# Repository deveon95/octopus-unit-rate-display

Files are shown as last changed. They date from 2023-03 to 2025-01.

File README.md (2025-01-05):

# Octopus Unit Rate Display for ESP32

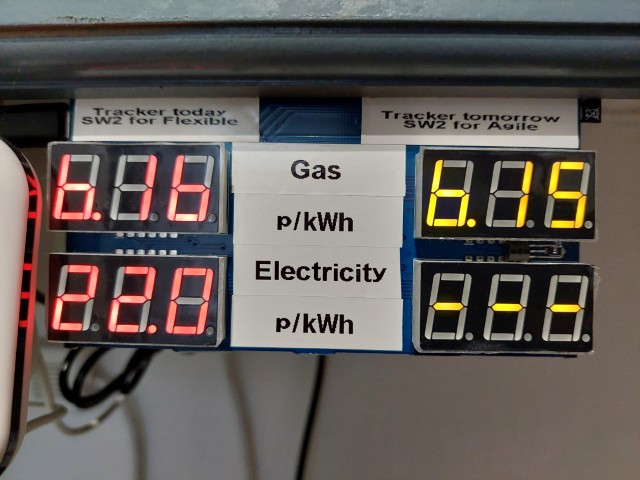
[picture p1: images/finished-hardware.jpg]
photo of the hardware


This project gets JSON data from https://octopus.energy

The JSON data is parsed and used to get today's gas and electricity unit rates for the **Tracker** tariff and/or the current **Flexible** prices and/or the current **Agile** prices.

Prices are displayed on two or more 3-digit 7-segment displays to two decimal places if the unit rate is less than 10.00, or one decimal place if the unit rate is greater than or equal to 10.00. Values greater than or equal to 100.00 are displayed with no decimal places.

Negative prices are also supported. In such an event, the first digit will be used for the '-' character.

# Installation

You'll need to install esp-idf to build this project.

```
git clone https://github.com/deveon95/octopus-unit-rate-display
cd esp-idf-json/json-http-client2
chmod 777 getpem.sh
./getpem.sh
idf.py menuconfig
idf.py build flash monitor
```

The getpem.sh script gets the https certificate for octopus.energy. HTTPS is mandatory to use the Octopus API, and this step cannot be skipped! The script does work on Windows as well as Linux; you can run the script with Windows Subsystem for Linux, and you may already be able to run it without installing anything extra if you've installed Git for Windows.

# Configuration
The configuration is opened by running idf.py menuconfig.

You'll need to set the wifi SSID and password so that the ESP32 can connect to the internet, and the tariff codes for the most accurate prices. Note that the latest version of the code has a few extra options for tariff codes not shown in the old screenshots because it has support for more tariffs. The 'ENABLE' options that show up in the latest version of the code should be set to 1 for tariffs that are desired to be displayed or 0 for tariffs to exclude.

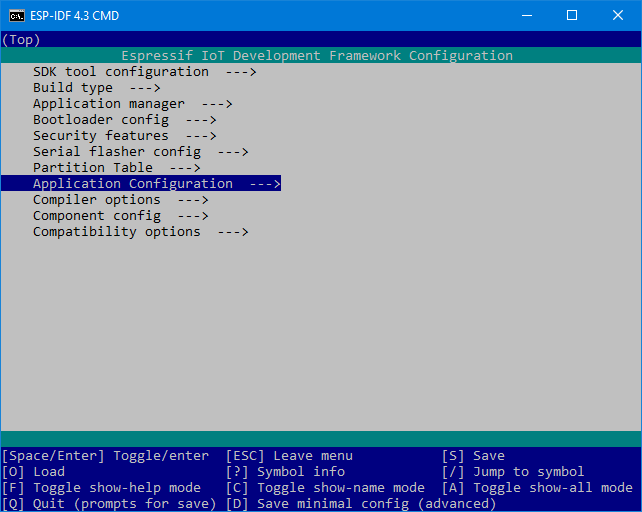
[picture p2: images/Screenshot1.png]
config-top

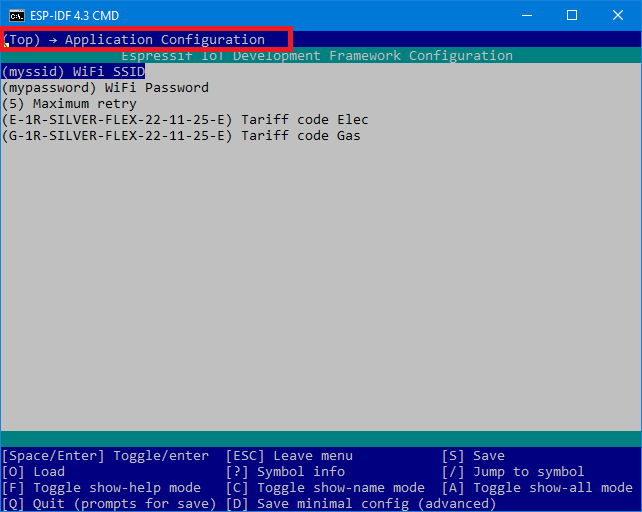
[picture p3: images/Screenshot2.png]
config-app


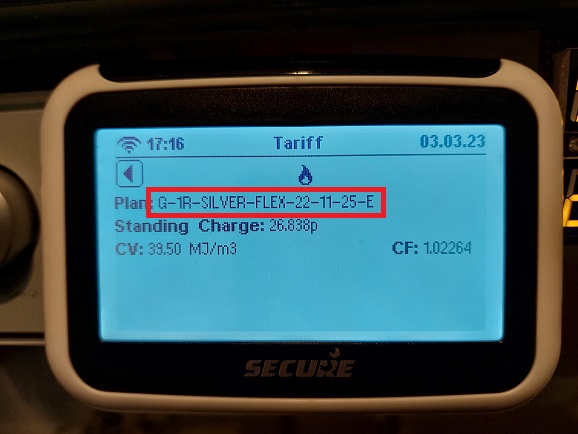
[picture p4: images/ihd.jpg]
finding the tariff on the ihd


To see the console output, set the log verbosity to Info. To disable console output, set to None.

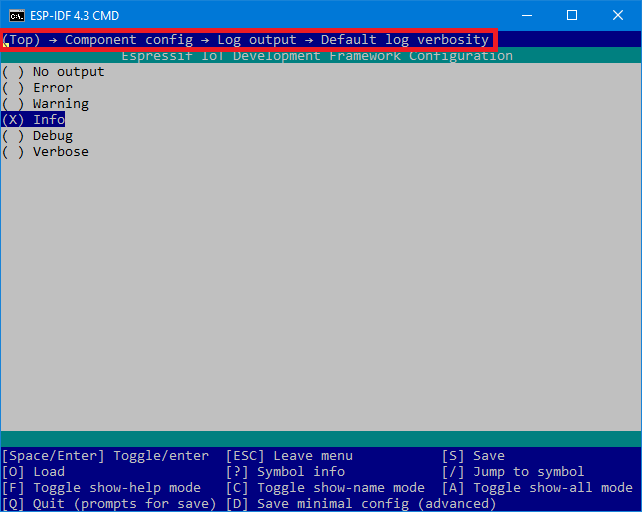
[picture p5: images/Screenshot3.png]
config-log


# Console output   
When enabled in the configuration, the console output will show all the unit rates returned by the server, usually for every day of the current month.

# Hardware schematic
See the KiCad design. The board can be mostly assembled by JLCPCB with displays of your choosing added by hand later.

The board and firmware supports up to 8 3-digit 7-segment displays. The lower half of the board can be broken off to give a more compact 4 display version shown in the photo.

For further details of the project, please see [my blog](https://nick-elec.blogspot.com/2023/03/esp32-based-octopus-tracker-unit-rate.html)

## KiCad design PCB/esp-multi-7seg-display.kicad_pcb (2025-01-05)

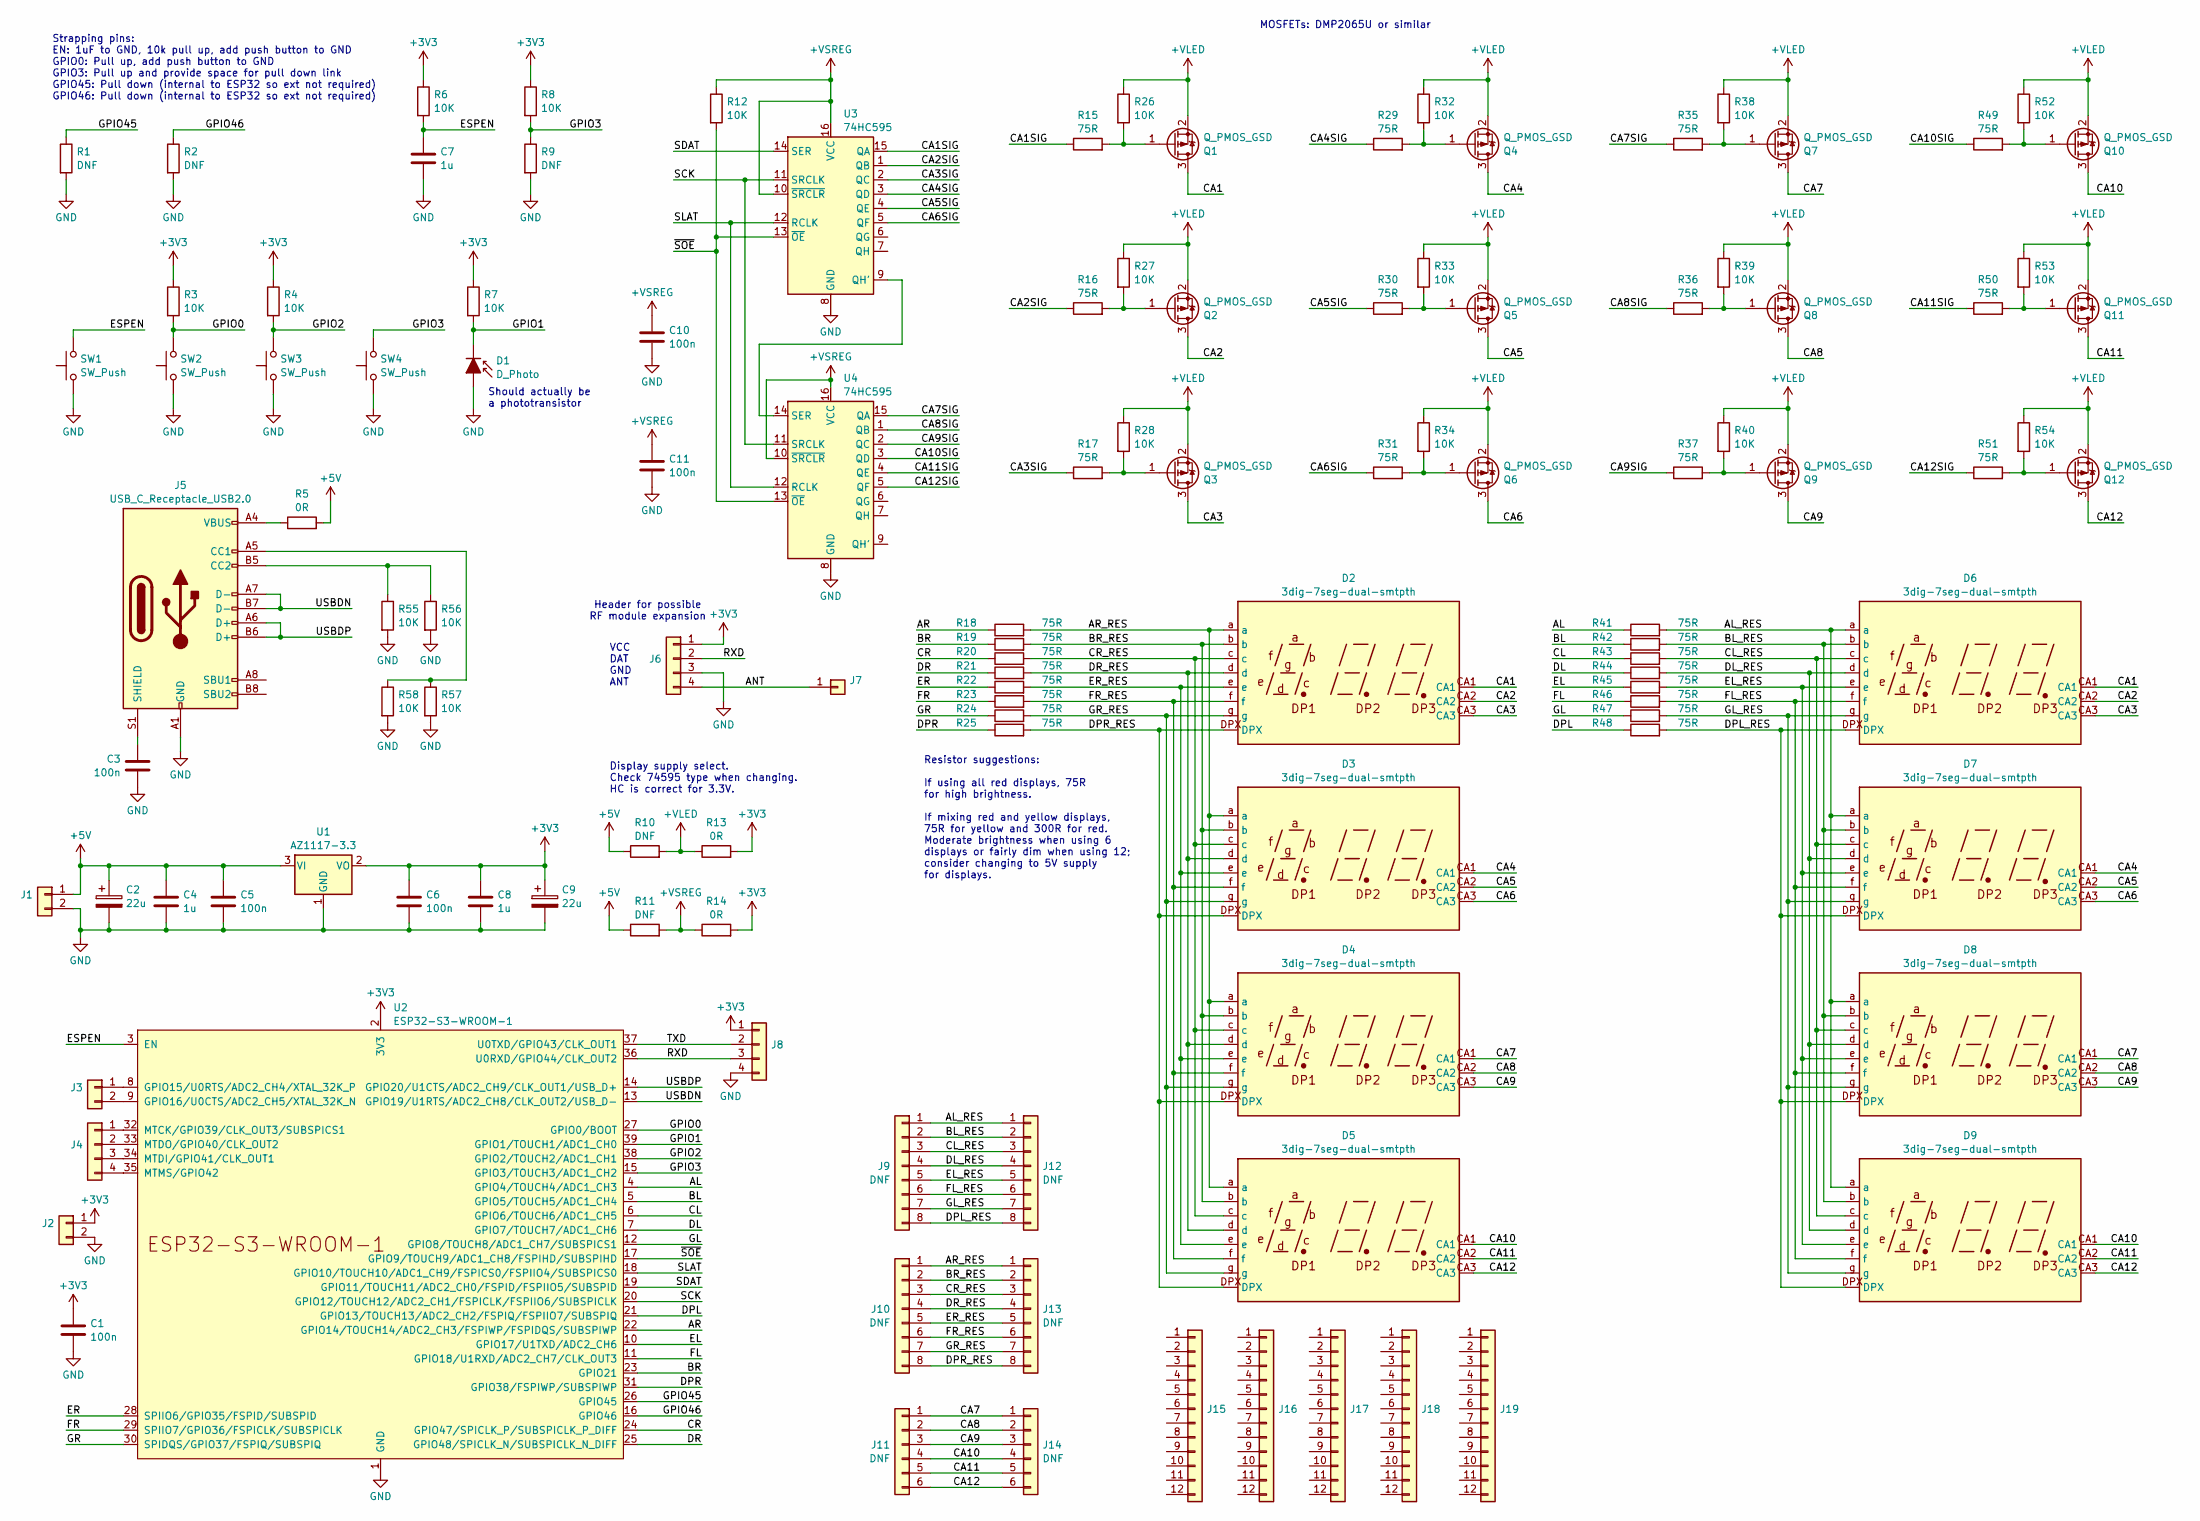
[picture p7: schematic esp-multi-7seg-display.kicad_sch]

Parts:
C1, C3, C5, C6, C10, C11: 100n; C_0603_1608Metric_Pad1.08x0.95mm_HandSolder; LCSC Part # C14663
C2, C9: 22u; CP_Elec_6.3x5.4; LCSC Part # C3646800
C4, C7, C8: 1u; C_0603_1608Metric_Pad1.08x0.95mm_HandSolder; LCSC Part # C15849
D1: D_Photo; LED_0805_2012Metric_Pad1.15x1.40mm_HandSolder
D2, D3, D4, D5, D6, D7, D8, D9: 3dig-7seg-dual-smtpth; LCSC Part # C226010
J1, J2, J3: DNF; PinHeader_1x02_P2.54mm_Vertical
J4, J6, J8: DNF; PinHeader_1x04_P2.54mm_Vertical
J5: USB_C_Receptacle_USB2.0; USB_C_Receptacle_G-Switch_GT-USB-7010ASV; LCSC Part # C2988369
J7: DNF; SolderWirePad_1x01_SMD_1x2mm
J9, J10, J12, J13: DNF; PinHeader_2x04_P2.54mm_Vertical_SMD
J11, J14: DNF; PinHeader_2x03_P2.54mm_Vertical_SMD
J15, J16, J17, J18, J19: DNF; PinHeader_1x12_P2.54mm_Vertical
Q1, Q2, Q3, Q4, Q5, Q6, Q7, Q8, Q9, Q10, Q11, Q12: Q_PMOS_GSD; SOT-23; LCSC Part # C10487
R1, R2, R9, R10, R11: DNF; R_0603_1608Metric_Pad0.98x0.95mm_HandSolder
R3, R4, R6, R7, R8, R12, R26, R27, R28, R32, R33, R34, R38, R39, R40, R52, R53, R54, R55, R56, R57, R58: 10K; R_0603_1608Metric_Pad0.98x0.95mm_HandSolder; LCSC Part # C465721
R5, R13, R14: 0R; R_0603_1608Metric_Pad0.98x0.95mm_HandSolder; LCSC Part # C103195
R15, R16, R17, R18, R19, R20, R21, R22, R23, R24, R25, R29, R30, R31, R35, R36, R37, R41, R42, R43, R44, R45, R46, R47, R48, R49, R50, R51: 75R; R_0603_1608Metric_Pad0.98x0.95mm_HandSolder; LCSC Part # C328376
SW1, SW2, SW3, SW4: SW_Push; SW_Push_1P1T_NO_6x6mm_H9.5mm; LCSC Part # C2909692
U1: AZ1117-3.3; SOT-223-3_TabPin2; LCSC Part # C6186
U2: ESP32-S3-WROOM-1; LCSC Part # C2913198
U3, U4: 74HC595; SO-16_5.3x10.2mm_P1.27mm; LCSC Part # C5947

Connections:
+3V3: C1.1, C6.1, C8.1, C9.1, J2.1, J6.1, J8.1, R3.1, R4.1, R6.1, R7.1, R8.1, R13.2, R14.2, U1.2 (VO), U2.2 (3V3)
+5V: C2.1, C4.1, C5.1, J1.1, R5.2, R10.1, R11.1, U1.3 (VI)
+VLED: Q1.2 (S), Q2.2 (S), Q3.2 (S), Q4.2 (S), Q5.2 (S), Q6.2 (S), Q7.2 (S), Q8.2 (S), Q9.2 (S), Q10.2 (S), Q11.2 (S), Q12.2 (S), R10.2, R13.1, R26.1, R27.1, R28.1, R32.1, R33.1, R34.1, R38.1, R39.1, R40.1, R52.1, R53.1, R54.1
+VSREG: C10.1, C11.1, R11.2, R12.1, R14.1, U3.10 (~SRCLR), U3.16 (VCC), U4.10 (~SRCLR), U4.16 (VCC)
/AL: R41.1, U2.4 (GPIO4/TOUCH4/ADC1_CH3)
/AL_RES: D6.a, D7.a, D8.a, D9.a, J9.1, J12.1, R41.2
/ANT: J6.4, J7.1
/AR: R18.1, U2.22 (GPIO14/TOUCH14/ADC2_CH3/FSPIWP/FSPIDQS/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)
/AR_RES: D2.a, D3.a, D4.a, D5.a, J10.1, J13.1, R18.2
/BL: R42.1, U2.5 (GPIO5/TOUCH5/ADC1_CH4)
/BL_RES: D6.b, D7.b, D8.b, D9.b, J9.2, J12.2, R42.2
/BR: R19.1, U2.23 (GPIO21)
/BR_RES: D2.b, D3.b, D4.b, D5.b, J10.2, J13.2, R19.2
/CA1: D2.CA1, D6.CA1, Q1.3 (D)
/CA1SIG: R15.1, U3.15 (QA)
/CA2: D2.CA2, D6.CA2, Q2.3 (D)
/CA2SIG: R16.1, U3.1 (QB)
/CA3: D2.CA3, D6.CA3, Q3.3 (D)
/CA3SIG: R17.1, U3.2 (QC)
/CA4: D3.CA1, D7.CA1, Q4.3 (D)
/CA4SIG: R29.1, U3.3 (QD)
/CA5: D3.CA2, D7.CA2, Q5.3 (D)
/CA5SIG: R30.1, U3.4 (QE)
/CA6: D3.CA3, D7.CA3, Q6.3 (D)
/CA6SIG: R31.1, U3.5 (QF)
/CA7: D4.CA1, D8.CA1, J11.1, J14.1, Q7.3 (D)
/CA7SIG: R35.1, U4.15 (QA)
/CA8: D4.CA2, D8.CA2, J11.2, J14.2, Q8.3 (D)
/CA8SIG: R36.1, U4.1 (QB)
/CA9: D4.CA3, D8.CA3, J11.3, J14.3, Q9.3 (D)
/CA9SIG: R37.1, U4.2 (QC)
/CA10: D5.CA1, D9.CA1, J11.4, J14.4, Q10.3 (D)
/CA10SIG: R49.1, U4.3 (QD)
/CA11: D5.CA2, D9.CA2, J11.5, J14.5, Q11.3 (D)
/CA11SIG: R50.1, U4.4 (QE)
/CA12: D5.CA3, D9.CA3, J11.6, J14.6, Q12.3 (D)
/CA12SIG: R51.1, U4.5 (QF)
/CL: R43.1, U2.6 (GPIO6/TOUCH6/ADC1_CH5)
/CL_RES: D6.c, D7.c, D8.c, D9.c, J9.3, J12.3, R43.2
/CR: R20.1, U2.24 (GPIO47/SPICLK_P/SUBSPICLK_P_DIFF)
/CR_RES: D2.c, D3.c, D4.c, D5.c, J10.3, J13.3, R20.2
/DL: R44.1, U2.7 (GPIO7/TOUCH7/ADC1_CH6)
/DL_RES: D6.d, D7.d, D8.d, D9.d, J9.4, J12.4, R44.2
/DPL: R48.1, U2.21 (GPIO13/TOUCH13/ADC2_CH2/FSPIQ/FSPIIO7/S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)
/DPL_RES: D6.DPX, D7.DPX, D8.DPX, D9.DPX, J9.8, J12.8, R48.2
/DPR: R25.1, U2.31 (GPIO38/FSPIWP/SUBSPIWP)
/DPR_RES: D2.DPX, D3.DPX, D4.DPX, D5.DPX, J10.8, J13.8, R25.2
/DR: R21.1, U2.25 (GPIO48/SPICLK_N/SUBSPICLK_N_DIFF)
/DR_RES: D2.d, D3.d, D4.d, D5.d, J10.4, J13.4, R21.2
/EL: R45.1, U2.10 (GPIO17/U1TXD/ADC2_CH6)
/EL_RES: D6.e, D7.e, D8.e, D9.e, J9.5, J12.5, R45.2
/ER: R22.1, U2.28 (SPIIO6/GPIO35/FSPID/SUBSPID)
/ER_RES: D2.e, D3.e, D4.e, D5.e, J10.5, J13.5, R22.2
/ESPEN: C7.1, R6.2, SW1.2, U2.3 (EN)
/FL: R46.1, U2.11 (GPIO18/U1RXD/ADC2_CH7/CLK_OUT3)
/FL_RES: D6.f, D7.f, D8.f, D9.f, J9.6, J12.6, R46.2
/FR: R23.1, U2.29 (SPIIO7/GPIO36/FSPICLK/SUBSPICLK)
/FR_RES: D2.f, D3.f, D4.f, D5.f, J10.6, J13.6, R23.2
/GL: R47.1, U2.12 (GPIO8/TOUCH8/ADC1_CH7/SUBSPICS1)
/GL_RES: D6.g, D7.g, D8.g, D9.g, J9.7, J12.7, R47.2
/GPIO0: R3.2, SW2.2, U2.27 (GPIO0/BOOT)
/GPIO1: D1.1 (K), R7.2, U2.39 (GPIO1/TOUCH1/ADC1_CH0)
/GPIO2: R4.2, SW3.2, U2.38 (GPIO2/TOUCH2/ADC1_CH1)
/GPIO3: R8.2, R9.1, SW4.2, U2.15 (GPIO3/TOUCH3/ADC1_CH2)
/GPIO45: R1.1, U2.26 (GPIO45)
/GPIO46: R2.1, U2.16 (GPIO46)
/GR: R24.1, U2.30 (SPIDQS/GPIO37/FSPIQ/SUBSPIQ)
/GR_RES: D2.g, D3.g, D4.g, D5.g, J10.7, J13.7, R24.2
/RXD: J6.2, J8.3, U2.36 (U0RXD/GPIO44/CLK_OUT2)
/SCK: U2.20 (GPIO12/TOUCH12/ADC2_CH1/FSPICLK/FSPIIO6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), U3.11 (SRCLK), U4.11 (SRCLK)
/SDAT: U2.19 (GPIO11/TOUCH11/ADC2_CH0/FSPID/FSPIIO5/S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), U3.14 (SER)
/SLAT: U2.18 (GPIO10/TOUCH10/ADC1_CH9/FSPICS0/FSPIIO4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), U3.12 (RCLK), U4.12 (RCLK)
/TXD: J8.2, U2.37 (U0TXD/GPIO43/CLK_OUT1)
/USBDN: J5.A7 (D-), J5.B7 (D-), U2.13 (GPIO19/U1RTS/ADC2_CH8/CLK_OUT2/USB_D-)
/USBDP: J5.A6 (D+), J5.B6 (D+), U2.14 (GPIO20/U1CTS/ADC2_CH9/CLK_OUT1/USB_D+)
/~SOE: R12.2, U2.17 (GPIO9/TOUCH9/ADC1_CH8/FSPIHD/SUBSPIHD), U3.13 (~OE), U4.13 (~OE)
GND: C1.2, C2.2, C3.2, C4.2, C5.2, C6.2, C7.2, C8.2, C9.2, C10.2, C11.2, D1.2 (A), J1.2, J2.2, J5.A1 (GND), J5.A12 (GND), J5.B1 (GND), J5.B12 (GND), J6.3, J8.4, R1.2, R2.2, R9.2, R55.2, R56.2, R57.2, R58.2, SW1.1, SW2.1, SW3.1, SW4.1, U1.1 (GND), U2.1 (GND), U2.40 (GND), U2.41 (GND), U3.8 (GND), U4.8 (GND)
unnamed: J3.1, U2.8 (GPIO15/U0RTS/ADC2_CH4/XTAL_32K_P)
unnamed: J3.2, U2.9 (GPIO16/U0CTS/ADC2_CH5/XTAL_32K_N)
unnamed: J4.1, U2.32 (MTCK/GPIO39/CLK_OUT3/SUBSPICS1)
unnamed: J4.2, U2.33 (MTDO/GPIO40/CLK_OUT2)
unnamed: J4.3, U2.34 (MTDI/GPIO41/CLK_OUT1)
unnamed: J4.4, U2.35 (MTMS/GPIO42)
unnamed: J5.A5 (CC1), R57.1, R58.1
unnamed: J5.B5 (CC2), R55.1, R56.1
unnamed: C3.1, J5.S1 (SHIELD)
unnamed: J5.A4 (VBUS), J5.A9 (VBUS), J5.B4 (VBUS), J5.B9 (VBUS), R5.1
unnamed: Q1.1 (G), R15.2, R26.2
unnamed: Q2.1 (G), R16.2, R27.2
unnamed: Q3.1 (G), R17.2, R28.2
unnamed: Q4.1 (G), R29.2, R32.2
unnamed: Q5.1 (G), R30.2, R33.2
unnamed: Q6.1 (G), R31.2, R34.2
unnamed: Q7.1 (G), R35.2, R38.2
unnamed: Q8.1 (G), R36.2, R39.2
unnamed: Q9.1 (G), R37.2, R40.2
unnamed: Q10.1 (G), R49.2, R52.2
unnamed: Q11.1 (G), R50.2, R53.2
unnamed: Q12.1 (G), R51.2, R54.2
unnamed: U3.9 (QH'), U4.14 (SER)

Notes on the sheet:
VCC DAT GND ANT
MOSFETs: DMP2065U or similar
Resistor suggestions: If using all red displays, 75R for high brightness. If mixing red and yellow displays, 75R for yellow and 300R for red. Moderate brightness when using 6 displays or fairly dim when using 12; consider changing to 5V supply for displays.
Header for possible RF module expansion
Should actually be a phototransistor
Strapping pins: EN: 1uF to GND, 10k pull up, add push button to GND GPIO0: Pull up, add push button to GND GPIO3: Pull up and provide space for pull down link GPIO45: Pull down (internal to ESP32 so ext not required) GPIO46: Pull down (internal to ESP32 so ext not required)
Display supply select. Check 74595 type when changing. HC is correct for 3.3V.

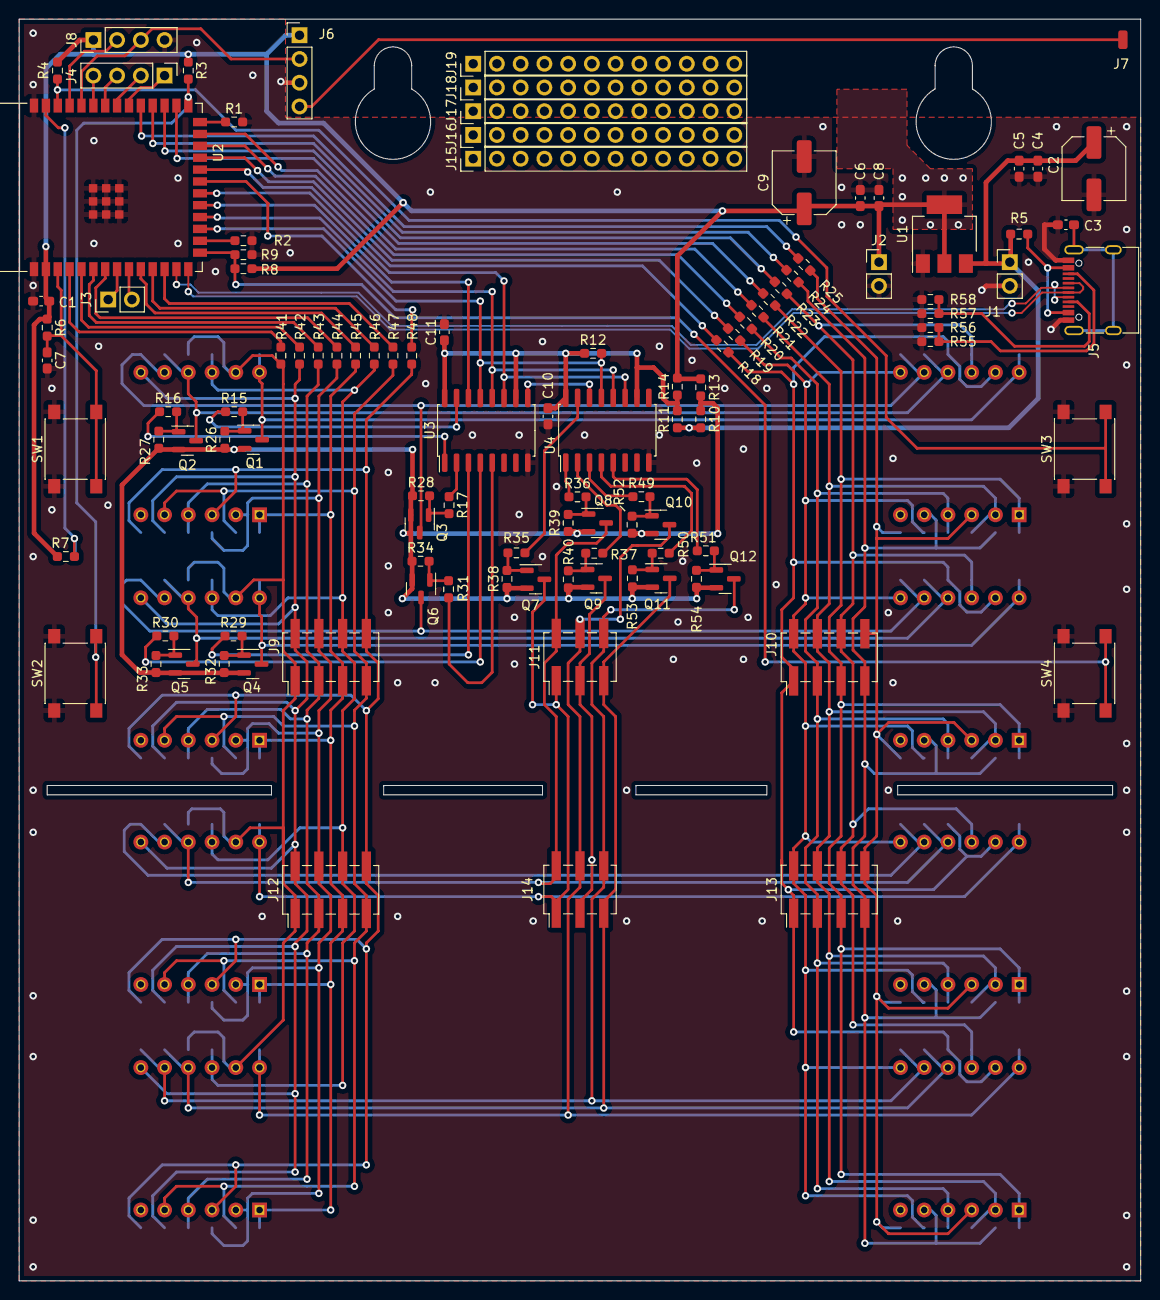
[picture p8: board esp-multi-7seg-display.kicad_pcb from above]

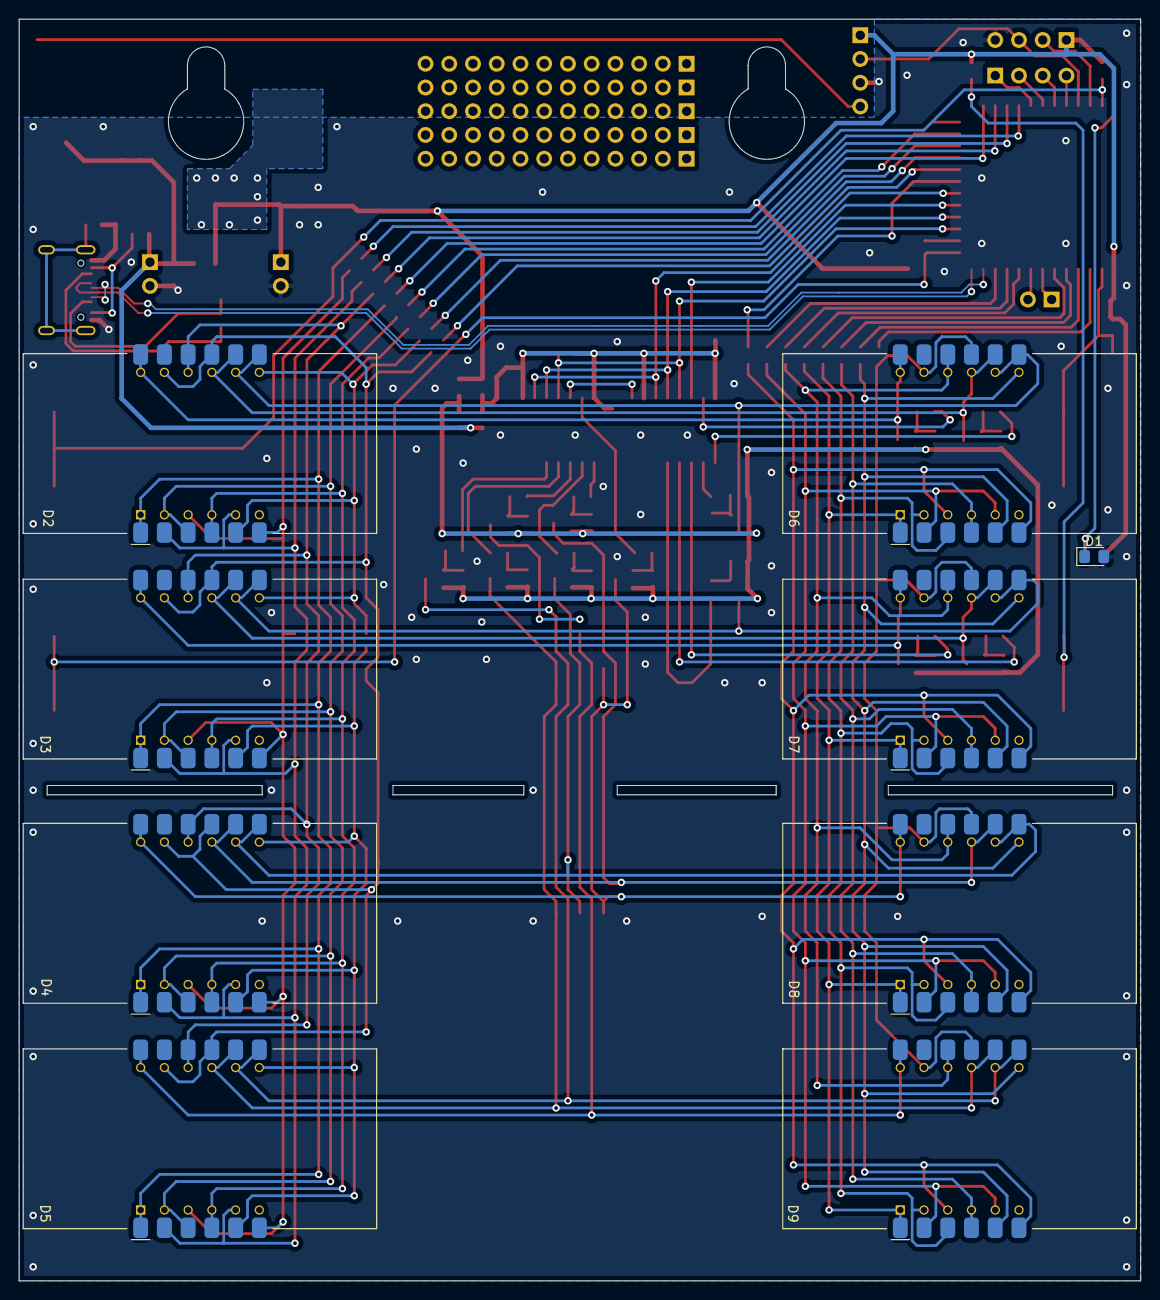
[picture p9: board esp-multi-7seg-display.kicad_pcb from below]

Board: 2 copper layers, 120.0 x 135.0 mm, 117 parts (9 on the bottom side), 100 nets.

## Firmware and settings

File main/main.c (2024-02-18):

/* Octopus Tracker Tariff Display for ESP32 / ESP-IDF
 *
 * Copyright (c) 2023 Nick Schollar
 * Licenced under MIT Licence
 *
 * Displays today's gas and electricity price for the tariff code specified in menuconfig
 * on two 3-digit common anode 7-segment displays. The tariff code is specific to your region.
 *
 * This program fetches the data from the server using a public API once per hour.
 * A certificate file is needed to connect to the server because HTTPS is mandatory.
 *
 * Wi-Fi SSID and password are specified in menuconfig.
 *
 * Self-diagnostics:
 * No dashes or decimal points: Program not running or displays connected incorrectly
 *   Check display wiring.
 * No dashes (only decimal points): Not connected to wifi
 *   Check SSID and password.
 * One dash on the display: Connected to wifi, time not synchronised yet
 *   Time is taken from HTTP response header, so this suggests unable to connect to internet.
 * Two dashes on the display: Time synchronised, prices not obtained yet
 *   API may have changed. Try tariff URL in a browser.
 */
#include "freertos/FreeRTOS.h"
#include "freertos/task.h"
#include "freertos/event_groups.h"
#include "freertos/ringbuf.h"
#include "esp_system.h"
#include "esp_wifi.h"
#include "esp_event.h"
#include "esp_log.h"
#include "nvs_flash.h"
#include "time.h"
#include "driver/gpio.h"
#include "hal/gpio_ll.h"
#include "driver/timer.h"
#include "driver/adc.h"

#include "lwip/err.h"
#include "lwip/sys.h"

#include "esp_http_client.h" 
#include "esp_tls.h" 
#include "cJSON.h"

#define SR_DELAY_US 1
#define NUM_OF_ANODES 16
#define ANODES_IN_USE 0b0000000000111111
//#define ANODES_IN_USE 0b0011111100111111

#define pin_segAR 14
#define pin_segBR 21
#define pin_segCR 47
#define pin_segDR 48
#define pin_segER 35
#define pin_segFR 36
#define pin_segGR 37
#define pin_segDPR 38
#define pin_segAL 4
#define pin_segBL 5
#define pin_segCL 6
#define pin_segDL 7
#define pin_segEL 17
#define pin_segFL 18
#define pin_segGL 8
#define pin_segDPL 13

#define pin_SOE 9
#define pin_SLAT 10
#define pin_SDAT 11
#define pin_SCK 12

#define pin_BUTTON2 0
#define pin_BUTTON3 2
#define pin_BUTTON4 3

#define TIMER_DIVIDER         (16)  //  Hardware timer clock divider
#define TIMER_SCALE           ((ets_get_apb_freq() / 10000)/ TIMER_DIVIDER)  // convert counter value to seconds

typedef struct {
    int timer_group;
    int timer_idx;
    int alarm_interval;
    bool auto_reload;
} timer_info_t;

//spi_device_handle_t spihandle;

// Set to True if the time was updated successfully
bool timeSet = false;
bool wifi_connected = false;
// Need to change this to separate ones for gas and elec
bool got_gas_unit_rate = false;
bool got_elec_unit_rate = false;
bool got_gas_tomorrow_unit_rate = false;
bool got_elec_tomorrow_unit_rate = false;
bool got_gas_flex_unit_rate = false;
bool got_elec_flex_unit_rate = false;
bool got_elec_agile_unit_rate = false;
#define TARIFF_TYPE_TRACKER 0
#define TARIFF_TYPE_FLEXIBLE 1
#define TARIFF_TYPE_AGILE 2
#define TARIFF_TYPE_TRACKER_TOMORROW 3

double gas_unit_rate = 0.0;
double elec_unit_rate = 0.0;
double gas_tomorrow_unit_rate = 0.0;
double elec_tomorrow_unit_rate = 0.0;
double gas_flex_unit_rate = 0.0;
double elec_flex_unit_rate = 0.0;
double elec_agile_rates[48];
uint64_t elec_agile_validity = 0;
uint8_t agile_time = 0;

#define FETCHER_WDOG_LIMIT_IN_SECONDS (60*15)

#define NUMBER_OF_BRIGHTNESS_SETTINGS 4
#define BRIGHTNESS_HYSTERESIS 100
// brightness of the display (0 to 3)
uint8_t display_brightness = 3;

#define ADC_FILTER_LENGTH 30
#define ADC_MAX_VALUE 4095
#define ADC_HYSTERESIS 200
static const adc_channel_t channel = ADC_CHANNEL_0;     //GPIO1 for ADC1
static const adc_bits_width_t width = ADC_WIDTH_BIT_12;
static const adc_atten_t atten = ADC_ATTEN_DB_11;
//static const adc_unit_t unit = ADC_UNIT_1;


/* FreeRTOS event group to signal when we are connected*/
static EventGroupHandle_t s_wifi_event_group;

/* The event group allows multiple bits for each event, but we only care about two events:
 * - we are connected to the AP with an IP
 * - we failed to connect after the maximum amount of retries */
#define WIFI_CONNECTED_BIT BIT0
#define WIFI_FAIL_BIT BIT1

static const char *TAG = "JSON";
static const char *TAG_FW = "FWD";
static const char *TAG_ADC = "ADC";

static int s_retry_num = 0;

/* Root cert for octopus.energy.com, taken from octopus_energy_root_cert.pem

	 The PEM file was extracted from the output of this command:
	 openssl s_client -showcerts -connect octopus.energy:443 </dev/null >hoge

	 The CA root cert is the last cert given in the chain of certs.

	 To embed it in the app binary, the PEM file is named
	 in the component.mk COMPONENT_EMBED_TXTFILES variable.
*/
extern const char octopus_energy_root_cert_pem_start[] asm("_binary_octopus_energy_root_cert_pem_start");
//extern const char octopus_energy_root_cert_pem_end[]	asm("_binary_octopus_energy_root_cert_pem_end");


esp_err_t _http_event_handler(esp_http_client_event_t *evt)
{
    struct tm time_struct;
    struct timeval timeval_struct;
    
	static char *output_buffer;  // Buffer to store response of http request from event handler
	static int output_len;		 // Stores number of bytes read
	switch(evt->event_id) {
		case HTTP_EVENT_ERROR:
			ESP_LOGD(TAG, "HTTP_EVENT_ERROR");
			break;
		case HTTP_EVENT_ON_CONNECTED:
			ESP_LOGD(TAG, "HTTP_EVENT_ON_CONNECTED");
			break;
		case HTTP_EVENT_HEADER_SENT:
			ESP_LOGD(TAG, "HTTP_EVENT_HEADER_SENT");
			break;
		case HTTP_EVENT_ON_HEADER:
			ESP_LOGD(TAG, "HTTP_EVENT_ON_HEADER, key=%s, value=%s", evt->header_key, evt->header_value);
            if (strcmp(evt->header_key, "Date") == 0)
            {
                ESP_LOGI(TAG, "Date header found: %s", evt->header_value);
                strptime(evt->header_value, "%a, %d %b %Y %H:%M:%S %Z", &time_struct);
                ESP_LOGI(TAG, "Time struct written: %d-%d-%d %d:%d:%d", time_struct.tm_year, time_struct.tm_mon, time_struct.tm_mday, time_struct.tm_hour, time_struct.tm_min, time_struct.tm_sec);
                timeval_struct.tv_sec = mktime(&time_struct);
                timeval_struct.tv_usec = 0;
                // tv_sec becomes -1 if mktime failed to convert the time struct into a time value
                if (timeval_struct.tv_sec > 0)
                {
                    timeSet = true;
                    ESP_LOGI(TAG, "RTC Seconds Since Epoch: %lld", timeval_struct.tv_sec);
                    ESP_LOGI(TAG, "RTC set, returned: %d", settimeofday(&timeval_struct, NULL));
                }
            }
			break;
		case HTTP_EVENT_ON_DATA:
			ESP_LOGD(TAG, "HTTP_EVENT_ON_DATA, len=%d", evt->data_len);
			//ESP_LOGD(TAG, "HTTP_EVENT_ON_DATA, content_length=%d", esp_http_client_get_content_length(evt->client));
			ESP_LOGD(TAG, "HTTP_EVENT_ON_DATA, output_len=%d", output_len);
			// If user_data buffer is configured, copy the response into the buffer
			if (evt->user_data) {
				memcpy(evt->user_data + output_len, evt->data, evt->data_len);
			} else {
				if (output_buffer == NULL && esp_http_client_get_content_length(evt->client) > 0) {
					output_buffer = (char *) malloc(esp_http_client_get_content_length(evt->client));
					output_len = 0;
					if (output_buffer == NULL) {
						ESP_LOGE(TAG, "Failed to allocate memory for output buffer");
						return ESP_FAIL;
					}
				}
				memcpy(output_buffer + output_len, evt->data, evt->data_len);
			}
			output_len += evt->data_len;
			break;
		case HTTP_EVENT_ON_FINISH:
			ESP_LOGD(TAG, "HTTP_EVENT_ON_FINISH");
			if (output_buffer != NULL) {
				// Response is accumulated in output_buffer. Uncomment the below line to print the accumulated response
				// ESP_LOG_BUFFER_HEX(TAG, output_buffer, output_len);
				free(output_buffer);
				output_buffer = NULL;
			}
			output_len = 0;
			break;
		case HTTP_EVENT_DISCONNECTED:
			ESP_LOGD(TAG, "HTTP_EVENT_DISCONNECTED");
			int mbedtls_err = 0;
			esp_err_t err = esp_tls_get_and_clear_last_error(evt->data, &mbedtls_err, NULL);
			if (err != 0) {
				if (output_buffer != NULL) {
					free(output_buffer);
					output_buffer = NULL;
				}
				output_len = 0;
				ESP_LOGE(TAG, "Last esp error code: 0x%x", err);
				ESP_LOGE(TAG, "Last mbedtls failure: 0x%x", mbedtls_err);
			}
			break;
#if ESP_IDF_VERSION >= ESP_IDF_VERSION_VAL(5, 0, 0)
		case HTTP_EVENT_REDIRECT:
			ESP_LOGD(TAG, "HTTP_EVENT_REDIRECT");
			break;
#endif
	}
	return ESP_OK;
}

static void event_handler(void* arg, esp_event_base_t event_base,
																int32_t event_id, void* event_data)
{
	if (event_base == WIFI_EVENT && event_id == WIFI_EVENT_STA_START) {
		esp_wifi_connect();
	} else if (event_base == WIFI_EVENT && event_id == WIFI_EVENT_STA_DISCONNECTED) {
		if (s_retry_num < CONFIG_ESP_MAXIMUM_RETRY) {
				esp_wifi_connect();
				s_retry_num++;
				ESP_LOGI(TAG, "retry to connect to the AP");
		} else {
				xEventGroupSetBits(s_wifi_event_group, WIFI_FAIL_BIT);
		}
		ESP_LOGI(TAG,"connect to the AP fail");
        wifi_connected = false;
	} else if (event_base == IP_EVENT && event_id == IP_EVENT_STA_GOT_IP) {
		ip_event_got_ip_t* event = (ip_event_got_ip_t*) event_data;
		ESP_LOGI(TAG, "got ip:" IPSTR, IP2STR(&event->ip_info.ip));
		s_retry_num = 0;
		xEventGroupSetBits(s_wifi_event_group, WIFI_CONNECTED_BIT);
        wifi_connected = true;
	}
}

void wifi_init_sta(void)
{
	s_wifi_event_group = xEventGroupCreate();

	ESP_ERROR_CHECK(esp_netif_init());

	ESP_ERROR_CHECK(esp_event_loop_create_default());
	esp_netif_create_default_wifi_sta();

	wifi_init_config_t cfg = WIFI_INIT_CONFIG_DEFAULT();
	ESP_ERROR_CHECK(esp_wifi_init(&cfg));

	esp_event_handler_instance_t instance_any_id;
	esp_event_handler_instance_t instance_got_ip;
	ESP_ERROR_CHECK(esp_event_handler_instance_register(WIFI_EVENT,
									ESP_EVENT_ANY_ID,
									&event_handler,
									NULL,
									&instance_any_id));
	ESP_ERROR_CHECK(esp_event_handler_instance_register(IP_EVENT,
									IP_EVENT_STA_GOT_IP,
									&event_handler,
									NULL,
									&instance_got_ip));

	wifi_config_t wifi_config = {
		.sta = {
			.ssid = CONFIG_ESP_WIFI_SSID,
			.password = CONFIG_ESP_WIFI_PASSWORD,
			/* Setting a password implies station will connect to all security modes including WEP/WPA.
			 * However these modes are deprecated and not advisable to be used. Incase your Access point
			 * doesn't support WPA2, these mode can be enabled by commenting below line */
			.threshold.authmode = WIFI_AUTH_WPA2_PSK,

			.pmf_cfg = {
				.capable = true,
				.required = false
			},
		},
	};
	ESP_ERROR_CHECK(esp_wifi_set_mode(WIFI_MODE_STA) );
	ESP_ERROR_CHECK(esp_wifi_set_config(WIFI_IF_STA, &wifi_config) );
	ESP_ERROR_CHECK(esp_wifi_start() );

	ESP_LOGI(TAG, "wifi_init_sta finished.");

	/* Waiting until either the connection is established (WIFI_CONNECTED_BIT) or connection failed for the maximum
	 * number of re-tries (WIFI_FAIL_BIT). The bits are set by event_handler() (see above) */
	EventBits_t bits = xEventGroupWaitBits(s_wifi_event_group,
		WIFI_CONNECTED_BIT | WIFI_FAIL_BIT,
		pdFALSE,
		pdFALSE,
		portMAX_DELAY);

	/* xEventGroupWaitBits() returns the bits before the call returned, hence we can test which event actually
	 * happened. */
	if (bits & WIFI_CONNECTED_BIT) {
		ESP_LOGI(TAG, "connected to ap SSID:%s password:%s", CONFIG_ESP_WIFI_SSID, CONFIG_ESP_WIFI_PASSWORD);
	} else if (bits & WIFI_FAIL_BIT) {
		ESP_LOGI(TAG, "Failed to connect to SSID:%s, password:%s", CONFIG_ESP_WIFI_SSID, CONFIG_ESP_WIFI_PASSWORD);
	} else {
		ESP_LOGE(TAG, "UNEXPECTED EVENT");
	}

	/* The event will not be processed after unregister */
	ESP_ERROR_CHECK(esp_event_handler_instance_unregister(IP_EVENT, IP_EVENT_STA_GOT_IP, instance_got_ip));
	ESP_ERROR_CHECK(esp_event_handler_instance_unregister(WIFI_EVENT, ESP_EVENT_ANY_ID, instance_any_id));
	vEventGroupDelete(s_wifi_event_group);
}

char *JSON_Types(int type) {
	if (type == cJSON_Invalid) return ("cJSON_Invalid");
	if (type == cJSON_False) return ("cJSON_False");
	if (type == cJSON_True) return ("cJSON_True");
	if (type == cJSON_NULL) return ("cJSON_NULL");
	if (type == cJSON_Number) return ("cJSON_Number");
	if (type == cJSON_String) return ("cJSON_String");
	if (type == cJSON_Array) return ("cJSON_Array");
	if (type == cJSON_Object) return ("cJSON_Object");
	if (type == cJSON_Raw) return ("cJSON_Raw");
	return NULL;
}


void JSON_Analyze(const cJSON * const root) {
	//ESP_LOGI(TAG, "root->type=%s", JSON_Types(root->type));
	cJSON *current_element = NULL;
	//ESP_LOGI(TAG, "roo->child=%p", root->child);
	//ESP_LOGI(TAG, "roo->next =%p", root->next);
	cJSON_ArrayForEach(current_element, root) {
		//ESP_LOGI(TAG, "type=%s", JSON_Types(current_element->type));
		//ESP_LOGI(TAG, "current_element->string=%p", current_element->string);
		if (current_element->string) {
			const char* string = current_element->string;
			ESP_LOGI(TAG, "[%s]", string);
		}
		if (cJSON_IsInvalid(current_element)) {
			ESP_LOGI(TAG, "Invalid");
		} else if (cJSON_IsFalse(current_element)) {
			ESP_LOGI(TAG, "False");
		} else if (cJSON_IsTrue(current_element)) {
			ESP_LOGI(TAG, "True");
		} else if (cJSON_IsNull(current_element)) {
			ESP_LOGI(TAG, "Null");
		} else if (cJSON_IsNumber(current_element)) {
			int valueint = current_element->valueint;
			double valuedouble = current_element->valuedouble;
			ESP_LOGI(TAG, "int=%d double=%f", valueint, valuedouble);
		} else if (cJSON_IsString(current_element)) {
			const char* valuestring = current_element->valuestring;
			ESP_LOGI(TAG, "%s", valuestring);
		} else if (cJSON_IsArray(current_element)) {
			//ESP_LOGI(TAG, "Array");
			JSON_Analyze(current_element);
		} else if (cJSON_IsObject(current_element)) {
			//ESP_LOGI(TAG, "Object");
			JSON_Analyze(current_element);
		} else if (cJSON_IsRaw(current_element)) {
			ESP_LOGI(TAG, "Raw(Not support)");
		}
	}
}

size_t http_client_content_length(char * url)
{
	ESP_LOGI(TAG, "http_client_content_length url=%s",url);
	size_t content_length;
	
	esp_http_client_config_t config = {
		.url = url,
		.event_handler = _http_event_handler,
		//.user_data = local_response_buffer,			 // Pass address of local buffer to get response
		.cert_pem = octopus_energy_root_cert_pem_start,
	};
	esp_http_client_handle_t client = esp_http_client_init(&config);

	// GET
	esp_err_t err = esp_http_client_perform(client);
	if (err == ESP_OK) {
#if ESP_IDF_VERSION >= ESP_IDF_VERSION_VAL(5, 0, 0)
		ESP_LOGD(TAG, "HTTP GET Status = %d, content_length = %lld",
#else
		ESP_LOGD(TAG, "HTTP GET Status = %d, content_length = %d",
#endif
				esp_http_client_get_status_code(client),
				esp_http_client_get_content_length(client));
		content_length = esp_http_client_get_content_length(client);

	} else {
		ESP_LOGW(TAG, "HTTP GET request failed: %s", esp_err_to_name(err));
		content_length = 0;
	}
	esp_http_client_cleanup(client);
	return content_length;
}

esp_err_t http_client_content_get(char * url, char * response_buffer)
{
	ESP_LOGI(TAG, "http_client_content_get url=%s",url);

	esp_http_client_config_t config = {
		.url = url,
		.event_handler = _http_event_handler,
		.user_data = response_buffer,			 // Pass address of local buffer to get response
		.cert_pem = octopus_energy_root_cert_pem_start,
	};
	esp_http_client_handle_t client = esp_http_client_init(&config);
    
    // err = esp_http_client_fetch_headers(client);
    //ESP_LOGI(TAG, "HTTP Client Fetch Headers returned %d", err);

	// GET
	esp_err_t err = esp_http_client_perform(client);
	if (err == ESP_OK) {
#if ESP_IDF_VERSION >= ESP_IDF_VERSION_VAL(5, 0, 0)
		ESP_LOGI(TAG, "HTTP GET Status = %d, content_length = %lld",
#else
		ESP_LOGI(TAG, "HTTP GET Status = %d, content_length = %d",
#endif
				esp_http_client_get_status_code(client),
				esp_http_client_get_content_length(client));
		ESP_LOGD(TAG, "\n%s", response_buffer);
	} else {
		ESP_LOGW(TAG, "HTTP GET request failed: %s", esp_err_to_name(err));
	}
    
    
	esp_http_client_cleanup(client);
	return err;
}

// Convert a date string into a struct tm
void date_string_to_struct_tm(const char *s, struct tm *time_struct)
{
     sscanf(
        s,
        "%d-%d-%dT%d-%d-%dZ",
        &time_struct->tm_year,
        &time_struct->tm_mon,
        &time_struct->tm_mday,
        &time_struct->tm_hour,
        &time_struct->tm_min,
        &time_struct->tm_sec
    );
    time_struct->tm_year -= 1900;
    time_struct->tm_mon--;
}
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
void app_main()
{
    ESP_LOGI("Reset reason: ", "%d", esp_reset_reason());
	//Initialize NVS
	esp_err_t ret = nvs_flash_init();
	if (ret == ESP_ERR_NVS_NO_FREE_PAGES || ret == ESP_ERR_NVS_NEW_VERSION_FOUND) {
		ESP_ERROR_CHECK(nvs_flash_erase());
		ret = nvs_flash_init();
	}
	ESP_ERROR_CHECK(ret);
    
    // Set up GPIO
    
    gpio_config_t io_conf;
    io_conf.intr_type = (gpio_int_type_t)GPIO_INTR_DISABLE;
    io_conf.mode = GPIO_MODE_OUTPUT;
    io_conf.pin_bit_mask = ((uint64_t)1 << pin_segAL)
                         | ((uint64_t)1 << pin_segBL)
                         | ((uint64_t)1 << pin_segCL)
                         | ((uint64_t)1 << pin_segDL)
                         | ((uint64_t)1 << pin_segEL)
                         | ((uint64_t)1 << pin_segFL)
                         | ((uint64_t)1 << pin_segGL)
                         | ((uint64_t)1 << pin_segDPL)
                         | ((uint64_t)1 << pin_segAR)
                         | ((uint64_t)1 << pin_segBR)
                         | ((uint64_t)1 << pin_segCR)
                         | ((uint64_t)1 << pin_segDR)
                         | ((uint64_t)1 << pin_segER)
                         | ((uint64_t)1 << pin_segFR)
                         | ((uint64_t)1 << pin_segGR)
                         | ((uint64_t)1 << pin_segDPR)
                         | ((uint64_t)1 << pin_SLAT)
                         | ((uint64_t)1 << pin_SOE)
                         | ((uint64_t)1 << pin_SDAT)
                         | ((uint64_t)1 << pin_SCK);
    io_conf.pull_down_en = GPIO_PULLDOWN_DISABLE;
    io_conf.pull_up_en = GPIO_PULLUP_DISABLE;
    ret = gpio_config(&io_conf);
    
	ESP_ERROR_CHECK(ret);
    
    /*
    spi_bus_config_t buscfg={
        .miso_io_num = -1,
        .mosi_io_num = pin_SDAT,
        .sclk_io_num = pin_SCK,
        .quadwp_io_num = -1,
        .quadhd_io_num = -1,
        .max_transfer_sz = 32,
    };
    //Initialize the SPI bus
    ret = spi_bus_initialize(SPI2_HOST, &buscfg, SPI_DMA_CH_AUTO);
    ESP_ERROR_CHECK(ret);
    
    spi_device_interface_config_t devcfg={
        .command_bits=16,
        .address_bits=0,
        .cs_ena_pretrans=2,
        .cs_ena_posttrans=2,
        .clock_speed_hz=1000000,
        .spics_io_num=pin_SLAT,
    }
    ret = spi_bus_add_device(SPi2_HOST, &devcfg, &spihandle);
    ESP_ERROR_CHECK(ret);
    */
    
    // FreeRTOS task setup
    
    TaskHandle_t getUnitRatesHandle;
    TaskHandle_t displayHandle;
    TaskHandle_t getLightLevelHandle;
    TaskHandle_t fetcherWatchdogHandle;
    
    xTaskCreatePinnedToCore(get_unit_rates_task, "get_unit_rates_task", 8192, NULL, configMAX_PRIORITIES - 3, &getUnitRatesHandle, 1);
    
    // Uncomment this task and comment out display_task below to test display with different values
    //xTaskCreatePinnedToCore(test_task, "test_task", 4096, NULL, configMAX_PRIORITIES - 3, &getUnitRatesHandle, 1);
    
    xTaskCreatePinnedToCore(display_task, "display_task", 2048, NULL, configMAX_PRIORITIES - 2, &displayHandle, 1);
    
    xTaskCreatePinnedToCore(fetcher_watchdog_task, "fetcher_watchdog_task", 4096, NULL, configMAX_PRIORITIES - 1, &fetcherWatchdogHandle, 1);
    
    xTaskCreatePinnedToCore(get_light_level_task, "get_light_level_task", 4096, NULL, configMAX_PRIORITIES - 4, &getLightLevelHandle, 1);

	while(1)
    {
        vTaskDelay(1000 / portTICK_PERIOD_MS);
    }
}

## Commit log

2023-10-14 Implemented shift registers for PCB version. Added flexible tariff price for comparison.
2023-12-22 Switched tracker API to latest API. *Warning: credentials are present in sdkconfig file, should be excluded from repo*
2023-12-23 Added display of tomorrow's tracker price, switched day calculation to use epoch time so that tracker should behave as expected during DST under new API
2025-01-05 Add PCB
    [esp-multi-7seg-display.kicad_pcb, esp-multi-7seg-display.kicad_sch]
2025-01-05 Update README.md to reflect addition of PCB design.

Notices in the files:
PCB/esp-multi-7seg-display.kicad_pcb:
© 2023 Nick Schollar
